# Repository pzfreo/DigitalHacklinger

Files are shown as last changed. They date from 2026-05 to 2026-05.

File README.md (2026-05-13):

# DigitalHacklinger

A magnetic thickness gauge for measuring instrument plates and purfling strips (1–5mm range) from one side only.

## Principle

A steel ball bearing is placed on the reverse face of the material. A neodymium magnet in the housing holds it through the material. Hall effect sensors detect the field perturbation to calculate thickness.

## Hardware

- Seeed XIAO ESP32S3
- ADC chip — not finalised (prototyping with the SparkX ADS1219 breakout)
- SS495A1 linear Hall effect sensors
- N52 neodymium magnet
- 3–4mm steel ball bearing
- LiPo battery + boost converter (5V rail)
- Small OLED display
- 3D printed nylon housing

## Repository Structure

- `firmware/` — ESP32S3 Arduino/PlatformIO code
- `hardware/` — 3D printed housing designs
- `docs/` — specs, calibration notes, test data

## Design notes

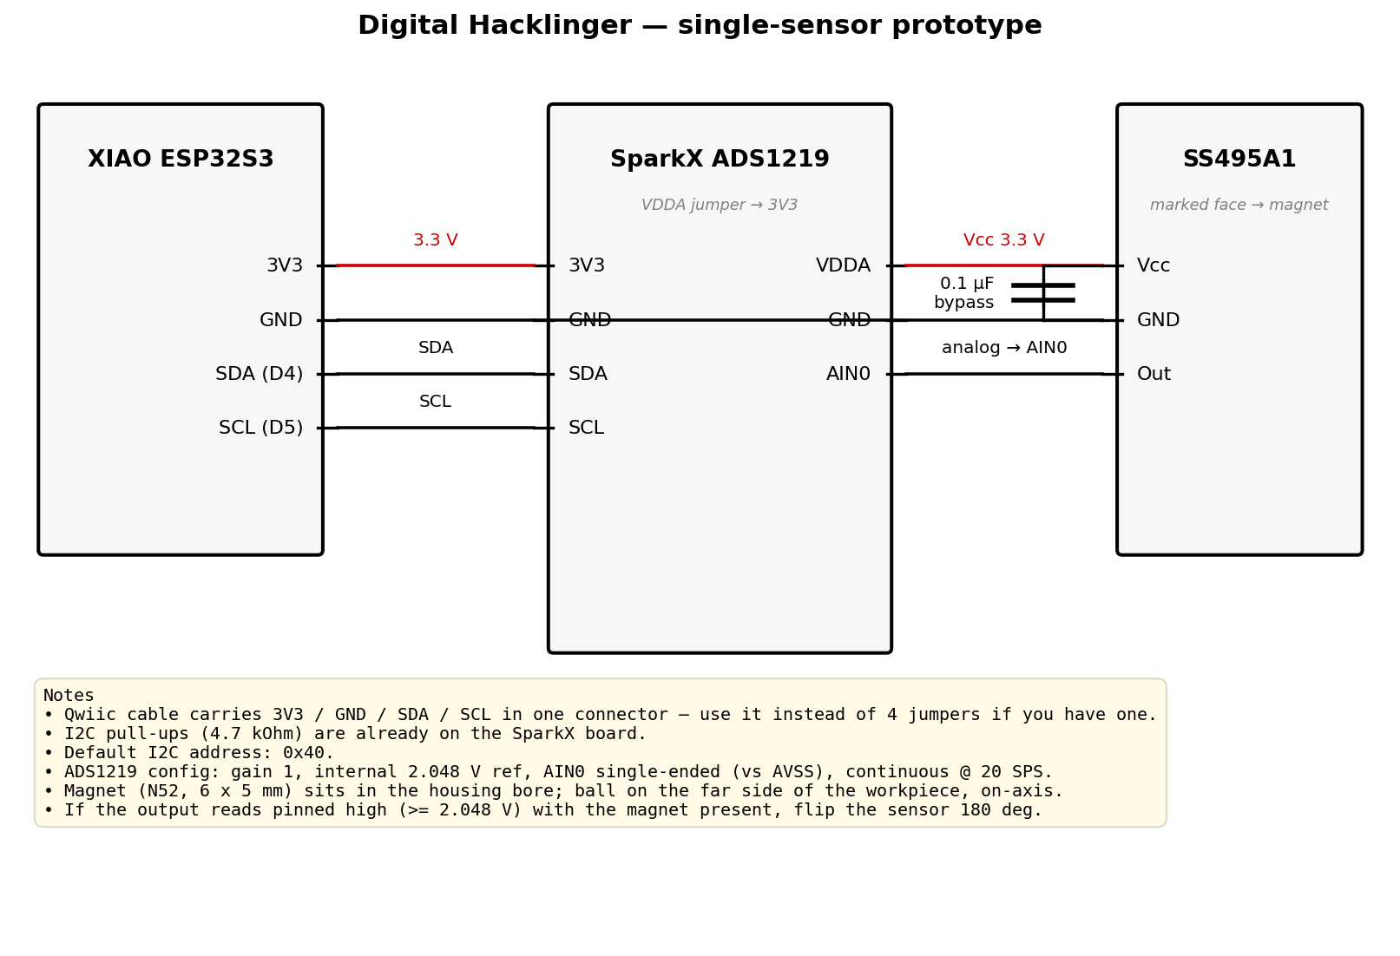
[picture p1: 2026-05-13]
hardware/schematic_proto.png

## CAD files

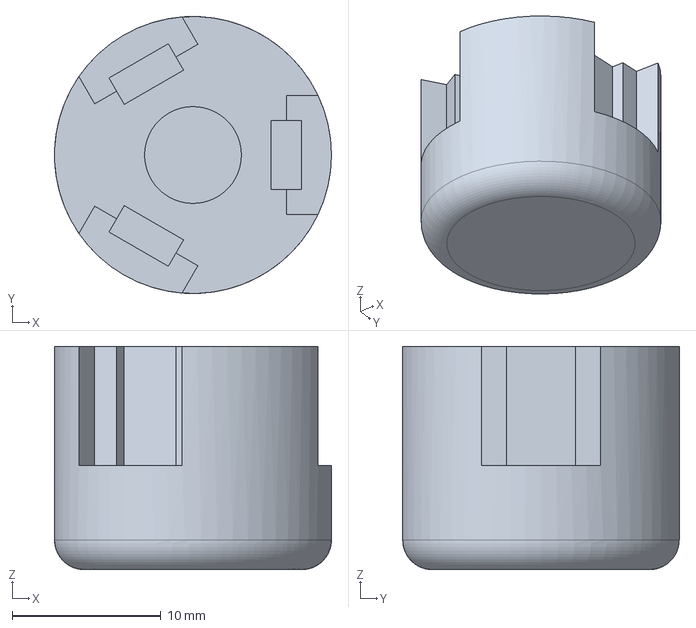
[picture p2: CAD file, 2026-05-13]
hardware/housing_tw2mm.step
18.6 x 18.6 x 15.0 mm

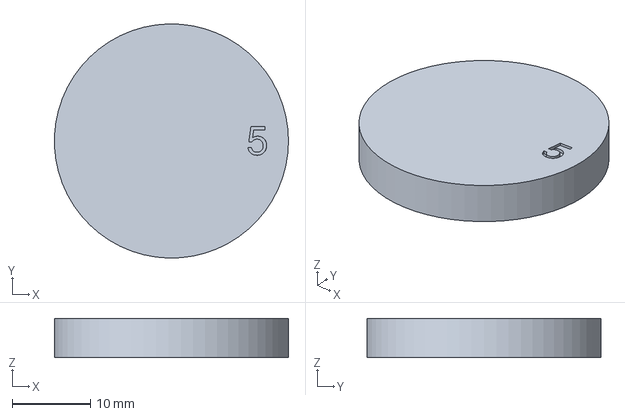
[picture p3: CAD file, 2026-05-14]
hardware/test_discs/disc_5mm.step
30.0 x 30.0 x 5.00 mm

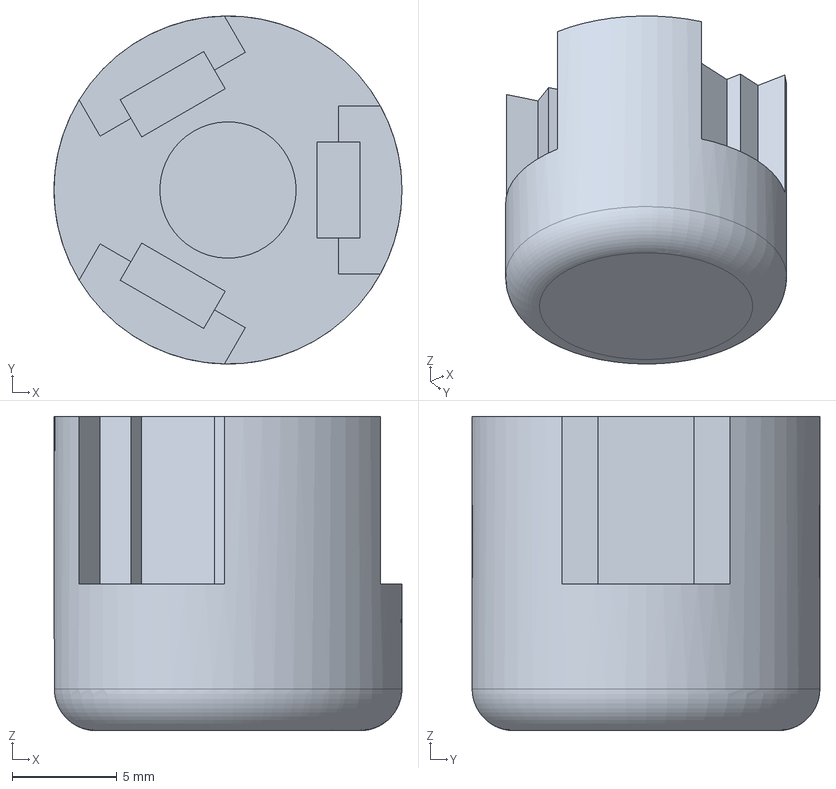
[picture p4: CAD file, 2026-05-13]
hardware/housing_tw1mm.step
16.6 x 16.6 x 15.0 mm

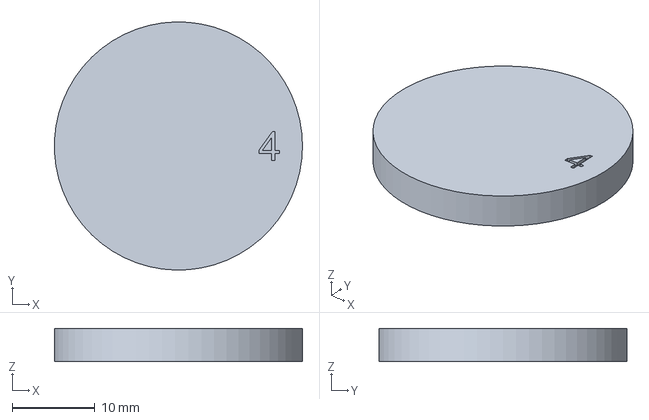
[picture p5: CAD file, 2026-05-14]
hardware/test_discs/disc_4mm.step
30.0 x 30.0 x 4.00 mm

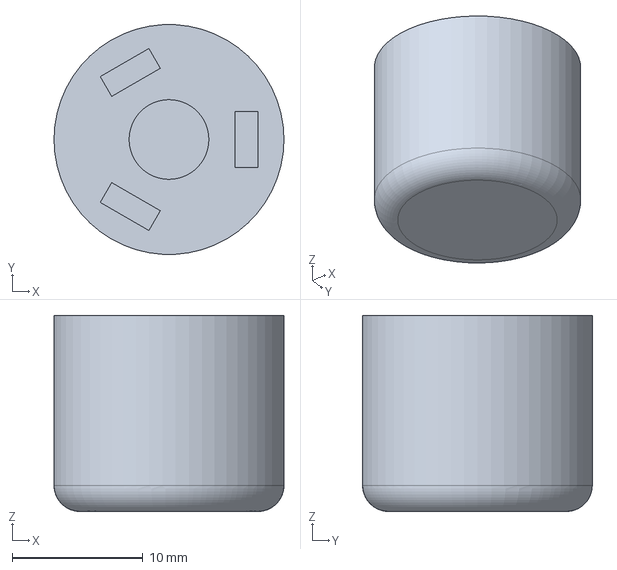
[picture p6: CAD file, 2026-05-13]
hardware/housing.step
17.6 x 17.6 x 15.0 mm

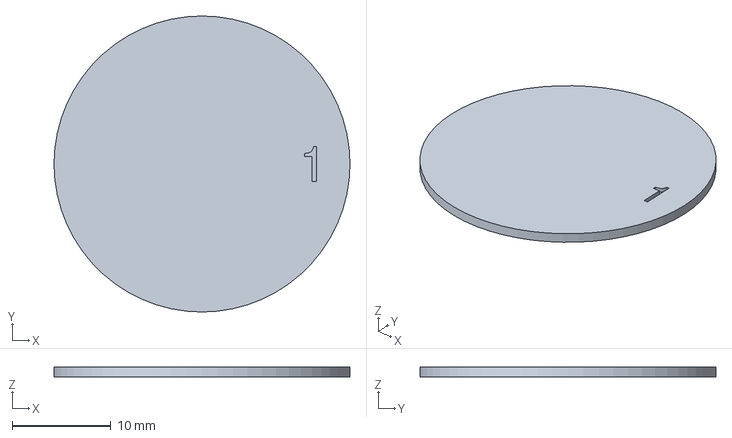
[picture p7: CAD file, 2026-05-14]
hardware/test_discs/disc_1mm.step
30.0 x 30.0 x 1.00 mm

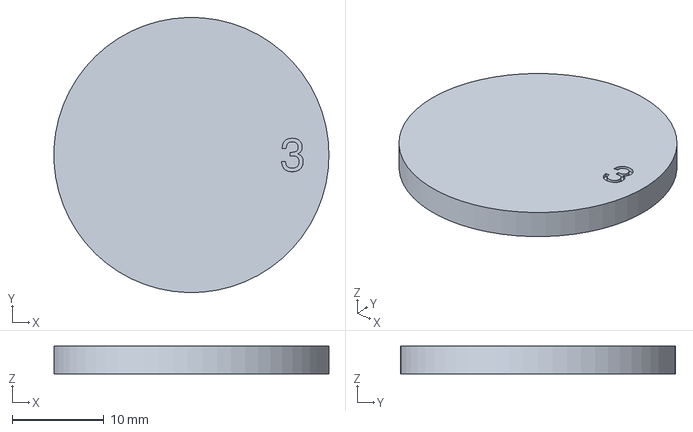
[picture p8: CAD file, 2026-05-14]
hardware/test_discs/disc_3mm.step
30.0 x 30.0 x 3.00 mm

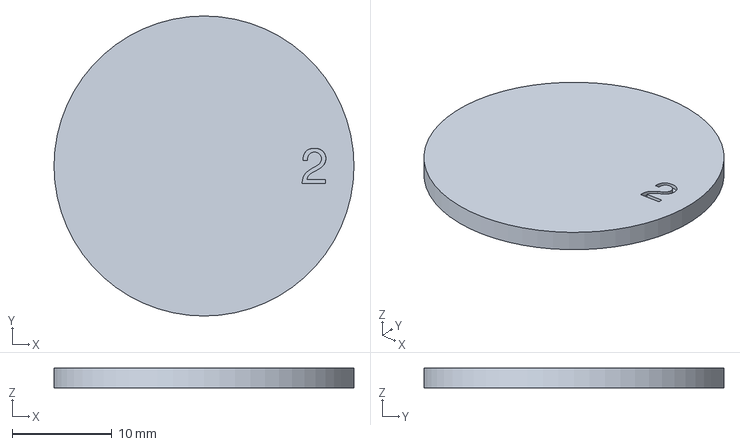
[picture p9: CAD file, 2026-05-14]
hardware/test_discs/disc_2mm.step
30.0 x 30.0 x 2.00 mm

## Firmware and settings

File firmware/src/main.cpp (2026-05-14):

// Digital Hacklinger — single-sensor bring-up.
// Reads SS495A1 → ADS1219 AIN0 single-ended; prints mean + stddev every 10 s.

#include <Arduino.h>
#include <Wire.h>
#include <math.h>

constexpr uint8_t ADS1219_ADDR  = 0x40;   // SparkX board default

// Commands (datasheet table 13)
constexpr uint8_t CMD_RESET     = 0x06;
constexpr uint8_t CMD_START     = 0x08;
constexpr uint8_t CMD_RDATA     = 0x10;
constexpr uint8_t CMD_WREG      = 0x40;

// Config register (datasheet table 14)
//   bits 7:5  MUX = 011  → AIN0 vs AVSS (single-ended)
//   bit  4    GAIN = 0   → 1×
//   bits 3:2  DR  = 00   → 20 SPS
//   bit  1    CM  = 1    → continuous conversions
//   bit  0    VREF = 0   → internal 2.048 V
constexpr uint8_t  CFG_VALUE    = (0b011 << 5) | (0 << 4) | (0b00 << 2) | (1 << 1) | 0;
constexpr float    VREF_MV      = 2048.0f;
constexpr float    FS_COUNTS    = 8388608.0f;   // 2^23 — single-ended range

constexpr uint32_t REPORT_MS    = 10000;        // print every 10 s
constexpr uint32_t SAMPLE_MS    = 50;           // matches 20 SPS

static void sendCmd(uint8_t cmd) {
  Wire.beginTransmission(ADS1219_ADDR);
  Wire.write(cmd);
  Wire.endTransmission();
}

static void writeConfig(uint8_t value) {
  Wire.beginTransmission(ADS1219_ADDR);
  Wire.write(CMD_WREG);
  Wire.write(value);
  Wire.endTransmission();
}

static int32_t readData() {
  Wire.beginTransmission(ADS1219_ADDR);
  Wire.write(CMD_RDATA);
  Wire.endTransmission();
  Wire.requestFrom((uint8_t)ADS1219_ADDR, (uint8_t)3);
  int32_t v = ((int32_t)Wire.read() << 16)
            | ((int32_t)Wire.read() << 8)
            |  (int32_t)Wire.read();
  if (v & 0x800000) v |= 0xFF000000;   // sign-extend 24 → 32
  return v;
}

// Welford accumulator — numerically stable mean/variance over the 10-s window.
static uint32_t n_samples       = 0;
static double   mean_mV         = 0.0;
static double   M2              = 0.0;
static uint32_t window_start_ms = 0;

void setup() {
  Serial.begin(115200);
  while (!Serial && millis() < 3000) {}
  Wire.begin();

  delay(50);
  sendCmd(CMD_RESET);
  delay(5);
  writeConfig(CFG_VALUE);
  sendCmd(CMD_START);
  delay(100);   // let the first 20-SPS conversion complete

  Serial.println("# every 10 s: n, mean_mV, sd_mV");
  window_start_ms = millis();
}

void loop() {
  int32_t raw = readData();
  double  mV  = ((double)raw / FS_COUNTS) * VREF_MV;

  // Welford online update
  n_samples++;
  double delta  = mV - mean_mV;
  mean_mV      += delta / n_samples;
  M2           += delta * (mV - mean_mV);

  if (millis() - window_start_ms >= REPORT_MS) {
    double sd = (n_samples > 1) ? sqrt(M2 / (n_samples - 1)) : 0.0;
    Serial.printf("n=%lu  mean=%.4f mV  sd=%.4f mV\n",
                  (unsigned long)n_samples, mean_mV, sd);
    n_samples       = 0;
    mean_mV         = 0.0;
    M2              = 0.0;
    window_start_ms = millis();
  }

  delay(SAMPLE_MS);
}

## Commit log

2026-04-30 Initial repo structure for magnetic thickness gauge
2026-04-30 Add build123d script for prototype sensor housing
    22.1mm diameter x 15mm tall. Central blind bore for 6mm N52 magnet
    (6.1mm bore, 0.1mm play). Three TO-92 slots at 120deg, flat face down,
    leads exit top. 1mm reference face disc retains magnet by gravity.
2026-04-30 Add generated STEP and STL for prototype housing
    Also fix export_step/export_stl to use standalone function form
    required by build123d 0.10.0.
    [housing.step, housing.stl]
2026-05-13 Update housing for SS495A1 SIP-3 sensors, fillet bottom, z=0 at base
    - Correct sensor package: 4.1 x 1.55 SIP-3 (was assumed TO-92)
    - Add 0.2mm slide-in clearance via SENSOR_FIT
    - Housing diameter shrinks from 22.1 to 17.6mm as a result
    - Rename TO92_W/D to SENSOR_W/D for accuracy
    - 2mm fillet on the bottom measurement-face outer edge
    - Shift coords so the bottom face is at z=0 (was centred on origin)
    Min wall at slot corner near the fillet zone is ~1.4mm; acceptable
    for a non-load-bearing nylon part.
    [housing.step, housing.stl]
2026-05-13 Emit two STEP variants (tube_wall 1mm and 2mm); drop STL outputs
    Wrap the model in a build(tube_wall) function and loop over both values
    to produce housing_tw1mm.step and housing_tw2mm.step for comparative
    print testing of sensor-to-magnet distance.
    STL files removed — only STEP is needed for downstream tooling.
    [housing.stl, housing_tw1mm.step, housing_tw2mm.step]
2026-05-13 Loosen magnet bore from 0.1mm to 0.5mm clearance for slide fit
    [housing_tw1mm.step, housing_tw2mm.step]
2026-05-13 README: defer ADC chip choice while prototyping
2026-05-13 Add single-sensor wiring schematic; correct sensor orientation note
    Schematic script + rendered PNG showing the XIAO ESP32S3 + ADS1219 +
    SS495A1 hookup for the bring-up prototype.
    Also fixes the housing comment: the SS495A1's sensitive face is the
    rounded (marked) side, not the flat side, so the assembly note now
    says "marked-face-inward".
2026-05-13 Firmware: single-sensor ADS1219 bring-up sketch (PlatformIO, XIAO ESP32S3)
    Minimal inline ADS1219 driver (no library) — reads AIN0 single-ended
    at 20 SPS continuous, internal 2.048 V reference, gain 1. Prints raw
    counts and millivolts at 20 Hz over USB serial.
    Enough to validate sensor + housing geometry on the bench before
    expanding to all three channels and adding ratiometric ref later.
2026-05-13 Add lead-exit cutout above each sensor slot; 6mm enclosed pocket
    Open the outer wall radially above each slot so soldered connectors
    can clear during insertion. Bottom 6mm of each slot stays fully
    enclosed (4-sided pocket), then the outer wall is cut through up to
    the top edge with an 8mm-wide tangential opening per slot.
    [housing_tw1mm.step, housing_tw2mm.step]
2026-05-14 Firmware: report mean and stddev over a 10-s window instead of per-sample
2026-05-14 Add 1-5mm calibration discs (build123d script + STEPs)
    [disc_1mm.step, disc_2mm.step, disc_3mm.step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]
